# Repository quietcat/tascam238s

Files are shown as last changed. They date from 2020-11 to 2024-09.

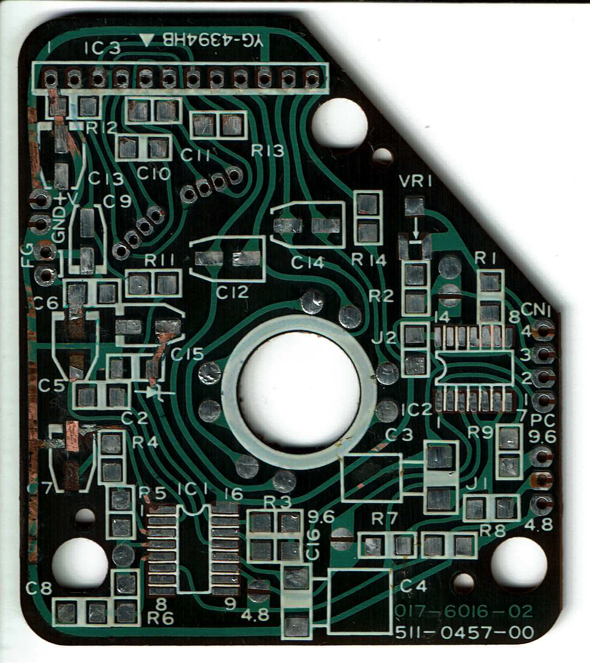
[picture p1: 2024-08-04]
capstan-pcb/238 capstan PCB 3.png

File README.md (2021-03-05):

# The Missing Tascam 238S Service Manual
Tascam 238S schematics and additional information. The Dolby S daughtercards are also used in Tascam MSR

## rp-amp-pcb

https://github.com/quietcat/tascam238s/blob/main/rp-amp-pcb.pdf

Contains Kicad schematics for the part of Tascam 238S channel PCB that is different from the dbx version

## dolby-hic

https://github.com/quietcat/tascam238s/blob/main/dolby-hic.pdf

Contains Kicad schematics for Dolby S NR HIC PCB, a Dolby encoder/decoder daughtercard for Tascam 238S

https://github.com/quietcat/tascam238s/tree/main/dolby-hic/gerbers contains Gerber files for a replacement Dolby PCB. The layout is different from the original, but functionally it is the same.

Visit https://238pro.com for more information on Tascam 238/238S repair and service

## 238S Calibration

First, calibrate the unit with Dolby S out.

Set all channels to recording mode, then press Pause and Record.

Feed -10 dBV/0 dBVU 400Hz (316 mV RMS) signal to the line inputs, and use ENC ADJ trimmer to adjust AC voltage on TP1 to be 388 mV.

Use ENC OUT trimmer to adjust AC voltage on REC LEVEL trimmer input lead (closest to the front) to be the same in both Dolby IN and OUT modes on each channel.

With Dolby S OUT, make a recording of -10 dBV/0 dBVU 400Hz test tone on all channels.

Set Dolby to IN, play back the recording and use DEC ADJ trimmer to adjust AC voltage on TP1 to be 388 mV on all channels.

Use DEC OUT trimmer to set voltage on the line out to -10 dBV (316 mV) on all channels.

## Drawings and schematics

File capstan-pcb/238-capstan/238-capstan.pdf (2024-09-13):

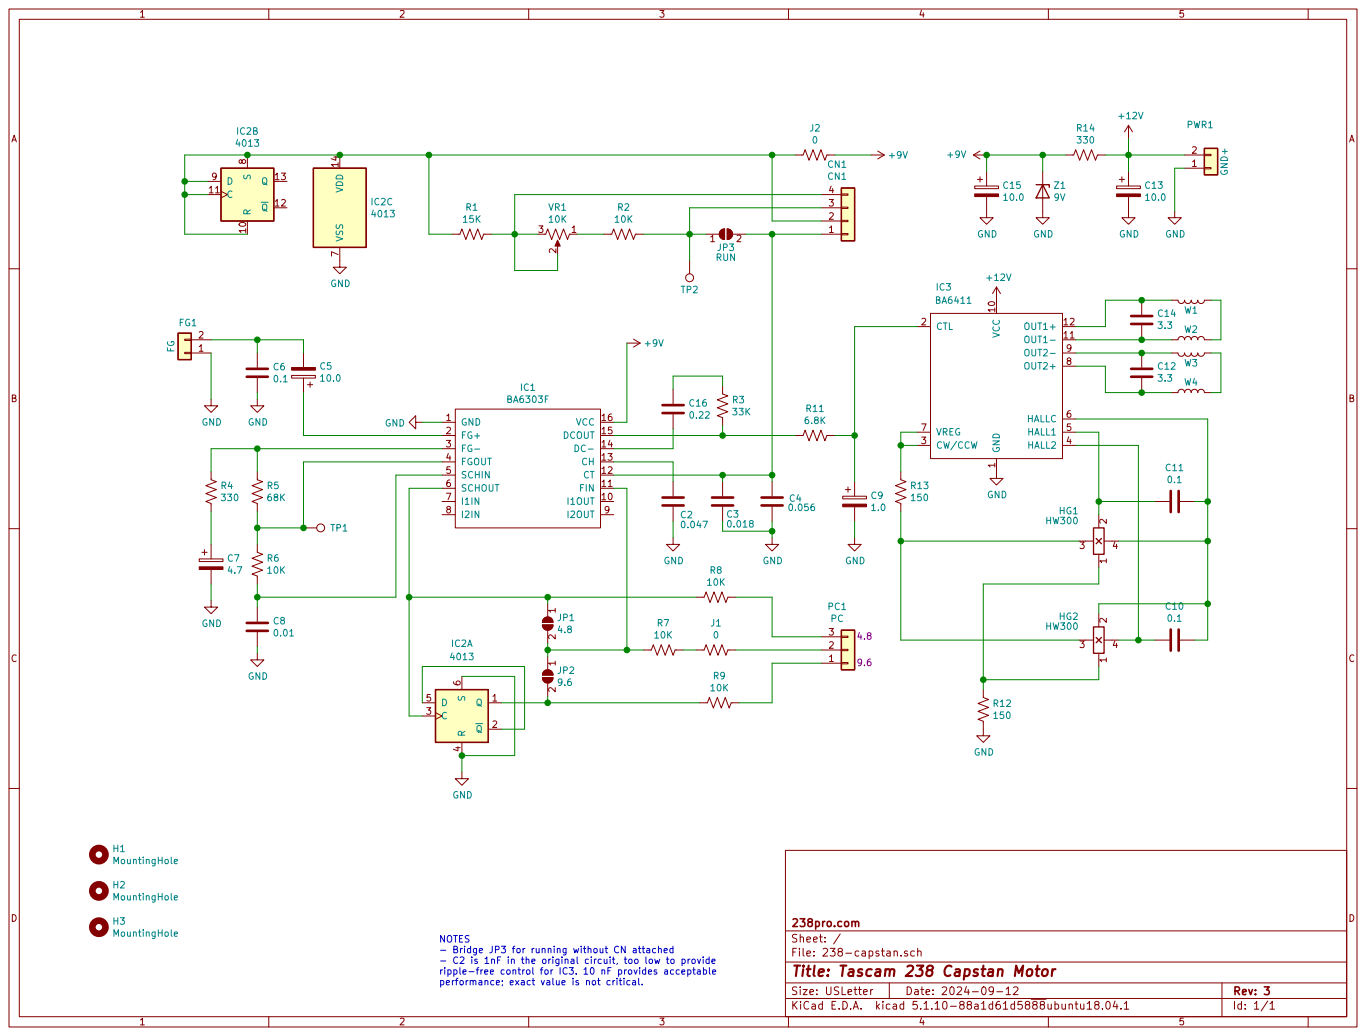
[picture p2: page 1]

1 VCC 10 OUT1- 11 OUT1+ 12 CTL 2 CW/CCW 3 HALL2 4 HALL1 5 HALLC 6 VREG 7 OUT2+ 8 OUT2- 9

File: 238-capstan.sch Sheet: / 238pro.com

NOTES
- Bridge JP3 for running without CN attached
- C2 is 1nF in the original circuit, too low to provide
ripple-free control for IC3. 10 nF provides acceptable
performance; exact value is not critical.

Id: 1/1 Title: Tascam 238 Capstan Motor

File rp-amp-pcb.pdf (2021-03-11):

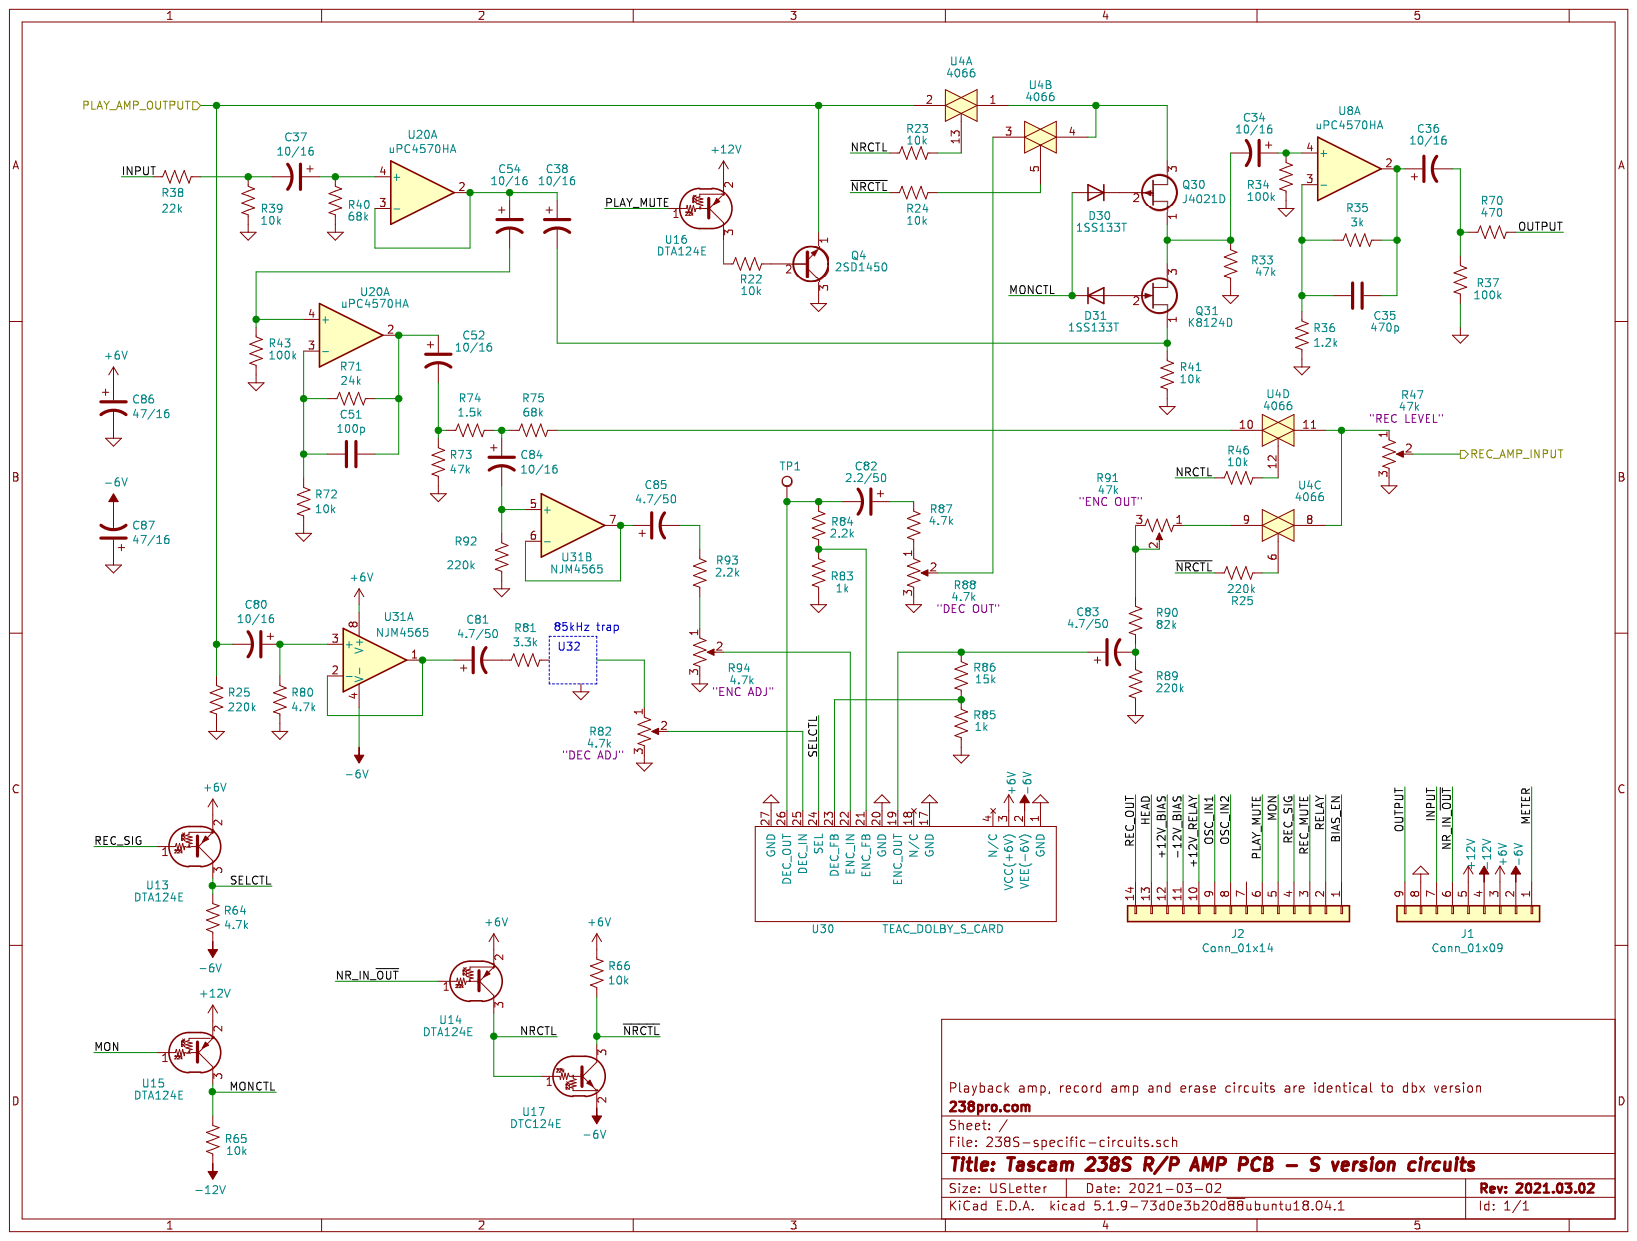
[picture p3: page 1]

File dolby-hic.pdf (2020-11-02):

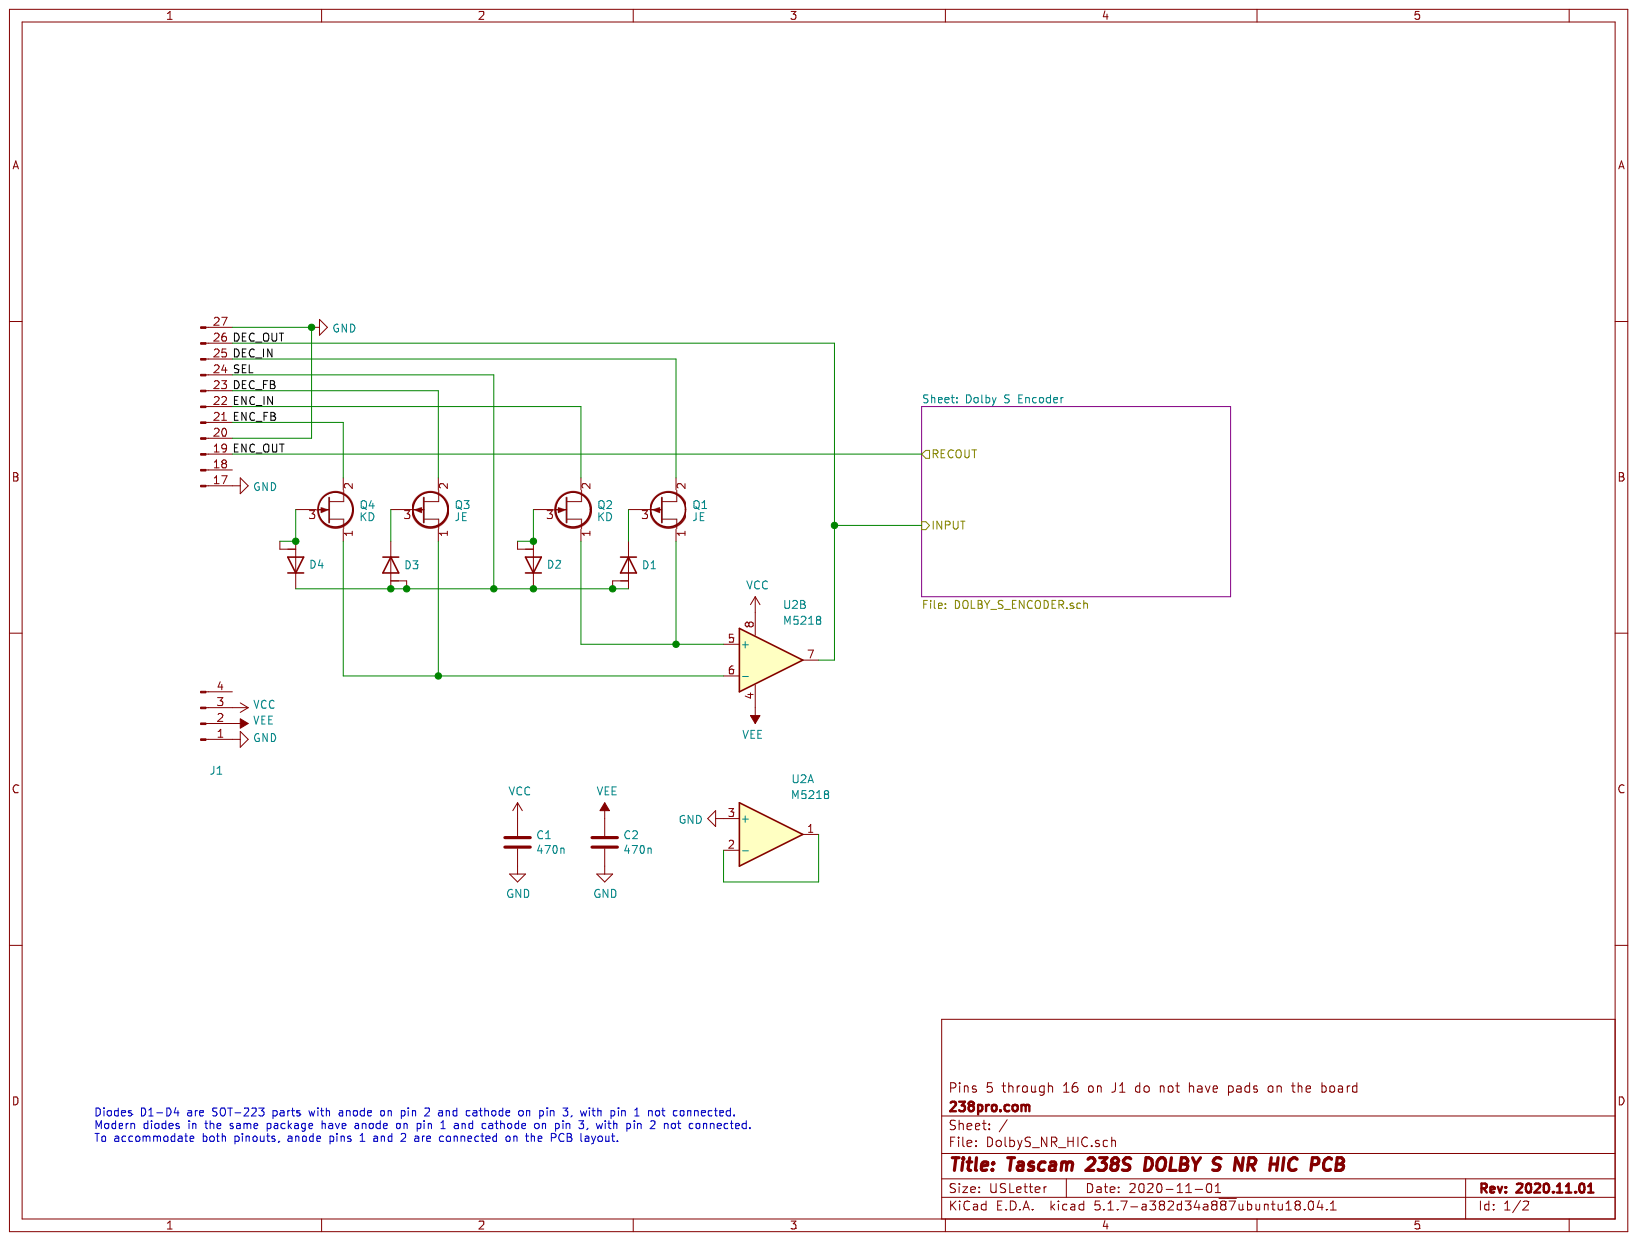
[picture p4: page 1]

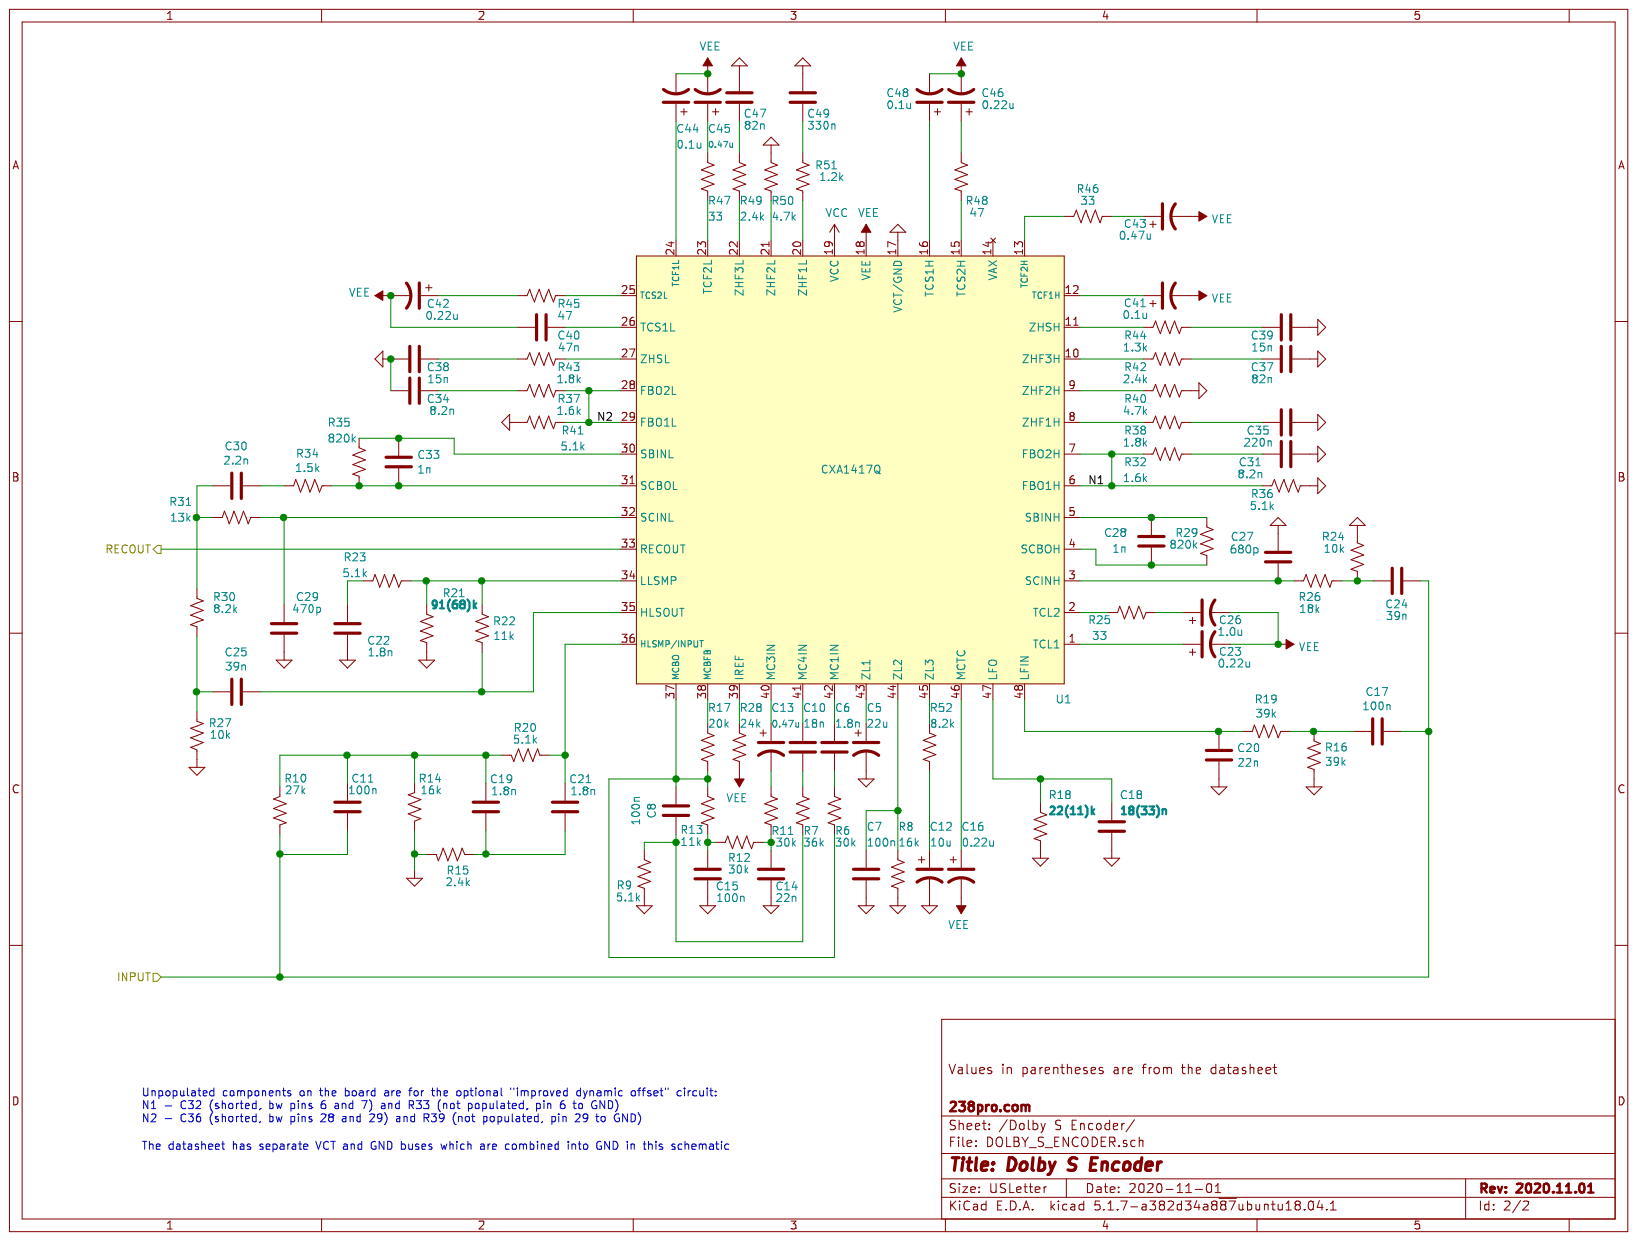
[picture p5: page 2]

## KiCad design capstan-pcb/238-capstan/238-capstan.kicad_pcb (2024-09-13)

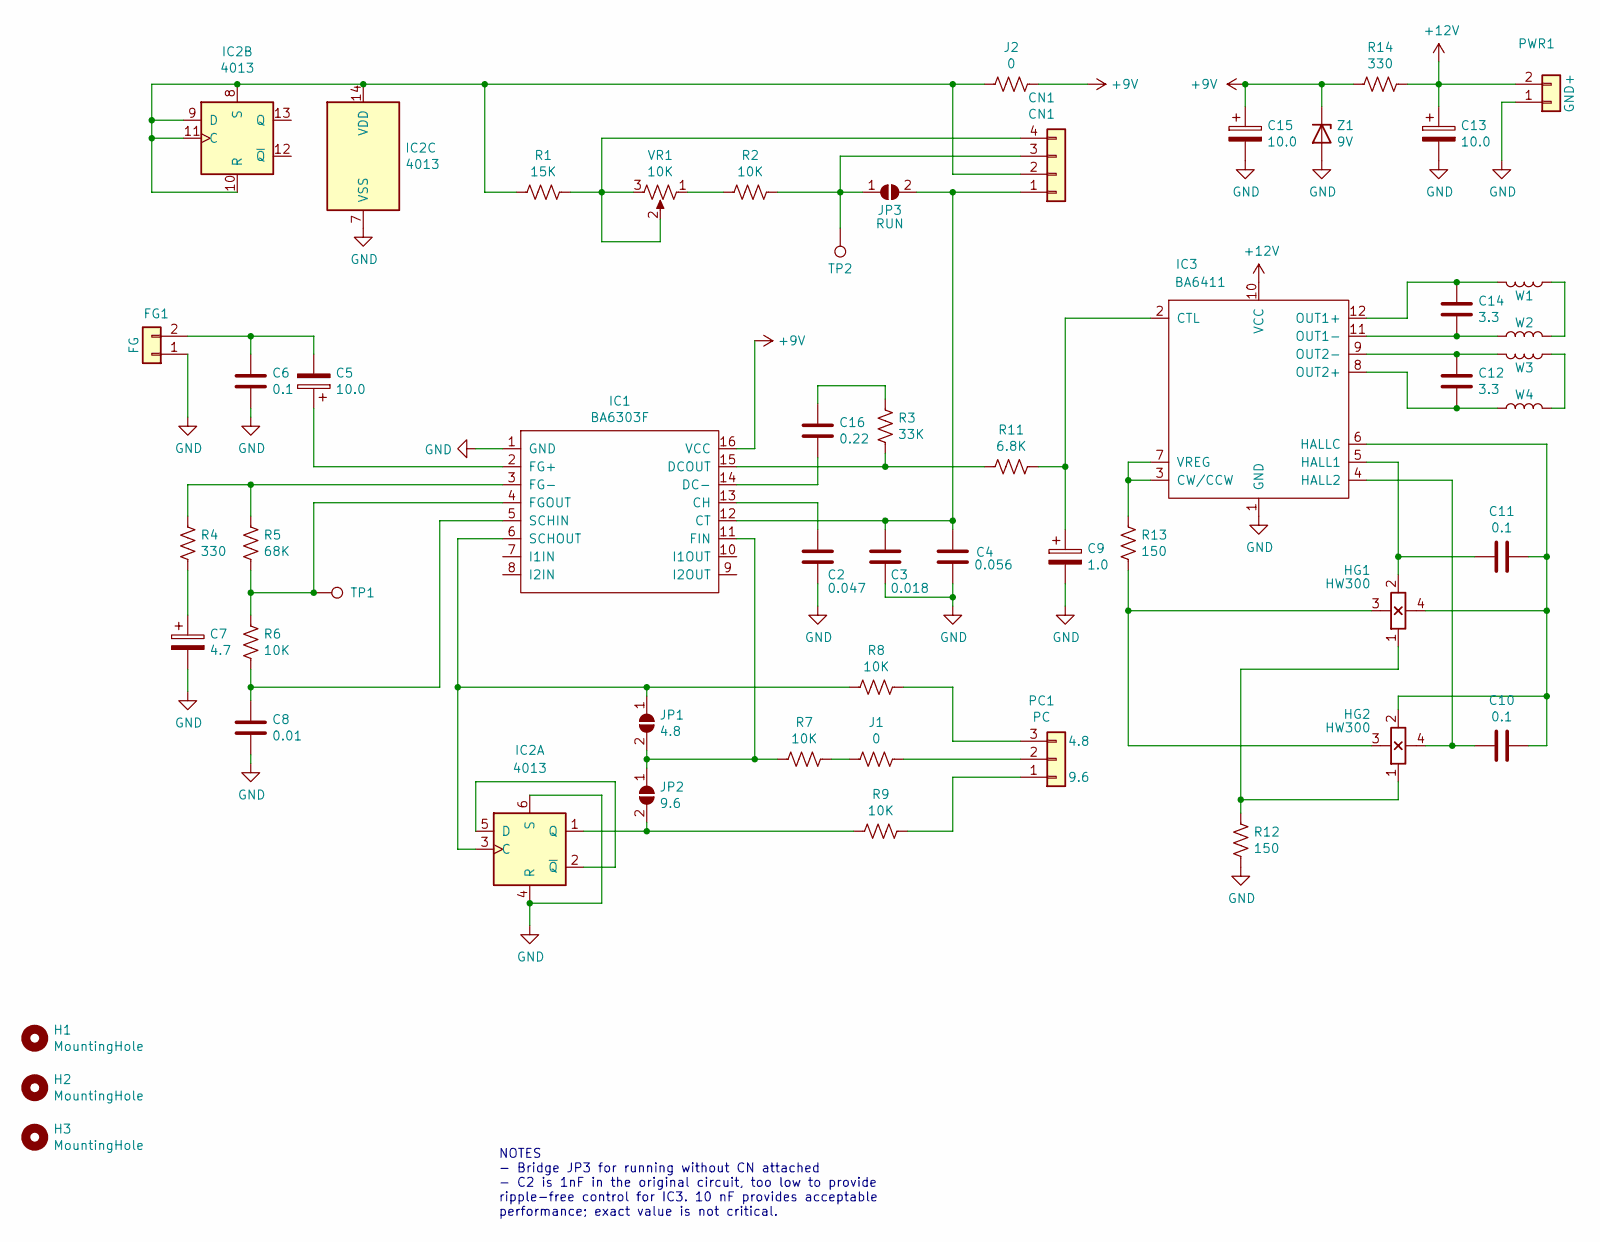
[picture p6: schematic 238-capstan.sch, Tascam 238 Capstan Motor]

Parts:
C2: 0.047; C_1206_3216Metric_Pad1.33x1.80mm_HandSolder
C3: 0.018; 238_C3
C4: 0.056; 238_C4
C5, C13, C15: 10.0; CP_Elec_4x5.3
C6, C10, C11: 0.1; C_1206_3216Metric_Pad1.33x1.80mm_HandSolder
C7: 4.7; CP_Elec_4x5.3
C8: 0.01; C_1206_3216Metric_Pad1.33x1.80mm_HandSolder
C9: 1.0; CP_Elec_4x5.3
C12, C14: 3.3; CP_Elec_4x5.3
C16: 0.22; C_1206_3216Metric_Pad1.33x1.80mm_HandSolder
CN1: CN1; 238_4_wire_conn
FG1: FG; 238_2_wire_conn
H1, H2, H3: MountingHole; MountingHole_2.1mm
HG1, HG2: HW300
IC1: BA6303F; SOIC-16_4.55x10.3mm_P1.27mm
IC2: 4013; SO-14_5.3x10.2mm_P1.27mm
IC3: BA6411
J1, J2: 0; R_1206_3216Metric_Pad1.30x1.75mm_HandSolder
JP1: 4.8; SolderJumper-2_P1.3mm_Open_RoundedPad1.0x1.5mm
JP2: 9.6; SolderJumper-2_P1.3mm_Open_RoundedPad1.0x1.5mm
JP3: RUN; SolderJumper-2_P1.3mm_Open_RoundedPad1.0x1.5mm
PC1: PC; 238_3_wire_conn
PWR1: GND+; 238_2_wire_conn
R1: 15K; R_1206_3216Metric_Pad1.30x1.75mm_HandSolder
R2, R6, R7, R8, R9: 10K; R_1206_3216Metric_Pad1.30x1.75mm_HandSolder
R3: 33K; R_1206_3216Metric_Pad1.30x1.75mm_HandSolder
R4, R14: 330; R_1206_3216Metric_Pad1.30x1.75mm_HandSolder
R5: 68K; R_1206_3216Metric_Pad1.30x1.75mm_HandSolder
R11: 6.8K; R_1206_3216Metric_Pad1.30x1.75mm_HandSolder
R12, R13: 150; R_1206_3216Metric_Pad1.30x1.75mm_HandSolder
TP1: TP1; TestPoint_Pad_D1.5mm
TP2: TP2; TestPoint_Pad_D2.5mm
VR1: 10K; Potentiometer_Bourns_TC33X_Vertical
W1, W2, W3, W4: W; 238_winding
Z1: 9V; D_MiniMELF

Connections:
+9V: C15.1, IC1.16 (VCC), J2.1, R14.2, Z1.1 (K)
+12V: C13.1, IC3.10 (VCC), PWR1.2, R14.1
GND: C2.2, C3.1, C4.2, C6.2, C7.2, C8.2, C9.2, C13.2, C15.2, FG1.1, IC1.1 (GND), IC2.4 (R), IC2.6 (S), IC2.7 (VSS), IC3.1 (GND), PWR1.1, R12.2, Z1.2 (A)
unnamed: C2.1, IC1.13 (CH)
unnamed: C3.2, C4.1, CN1.1, IC1.12 (CT), JP3.2 (B)
unnamed: C5.1, IC1.2 (FG+)
unnamed: C5.2, C6.1, FG1.2
unnamed: C7.1, R4.2
unnamed: C8.1, IC1.5 (SCHIN), R6.2
unnamed: C9.1, IC3.2 (CTL), R11.1
unnamed: C10.1, HG2.4 (UH2), IC3.4 (HALL2)
unnamed: C10.2, C11.2, HG1.4 (UH2), HG2.2 (U2), IC3.6 (HALLC)
unnamed: C11.1, HG1.2 (U2), IC3.5 (HALL1)
unnamed: C12.1, IC3.8 (OUT2+), W4.1
unnamed: C12.2, IC3.9 (OUT2-), W3.2
unnamed: C14.1, IC3.11 (OUT1-), W2.1
unnamed: C14.2, IC3.12 (OUT1+), W1.2
unnamed: C16.1, R3.1
unnamed: C16.2, IC1.14 (DC-)
unnamed: CN1.2, IC2.8 (S), IC2.9 (D), IC2.10 (R), IC2.11 (C), IC2.14 (VDD), J2.2, R1.2
unnamed: CN1.3, JP3.1 (A), R2.1, TP2.1
unnamed: CN1.4, R1.1, VR1.2, VR1.3
unnamed: HG1.1 (U1), HG2.1 (U1), R12.1
unnamed: HG1.3 (UH1), HG2.3 (UH1), R13.2
unnamed: IC1.3 (FG-), R4.1, R5.1
unnamed: IC1.4 (FGOUT), R5.2, R6.1, TP1.1
unnamed: IC1.6 (SCHOUT), IC2.3 (C), JP1.1 (A), R8.2
unnamed: IC1.11 (FIN), JP1.2 (B), JP2.1 (A), R7.2
unnamed: IC1.15 (DCOUT), R3.2, R11.2
unnamed: IC2.1 (Q), JP2.2 (B), R9.2
unnamed: IC2.2 (~Q), IC2.5 (D)
unnamed: IC3.3 (CW/CCW), IC3.7 (VREG), R13.1
unnamed: J1.1, PC1.2
unnamed: J1.2, R7.1
unnamed: PC1.1, R9.1
unnamed: PC1.3, R8.1
unnamed: R2.2, VR1.1
unnamed: W1.1, W2.2
unnamed: W3.1, W4.2

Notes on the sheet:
NOTES - Bridge JP3 for running without CN attached - C2 is 1nF in the original circuit, too low to provide ripple-free control for IC3. 10 nF provides acceptable performance; exact value is not critical.

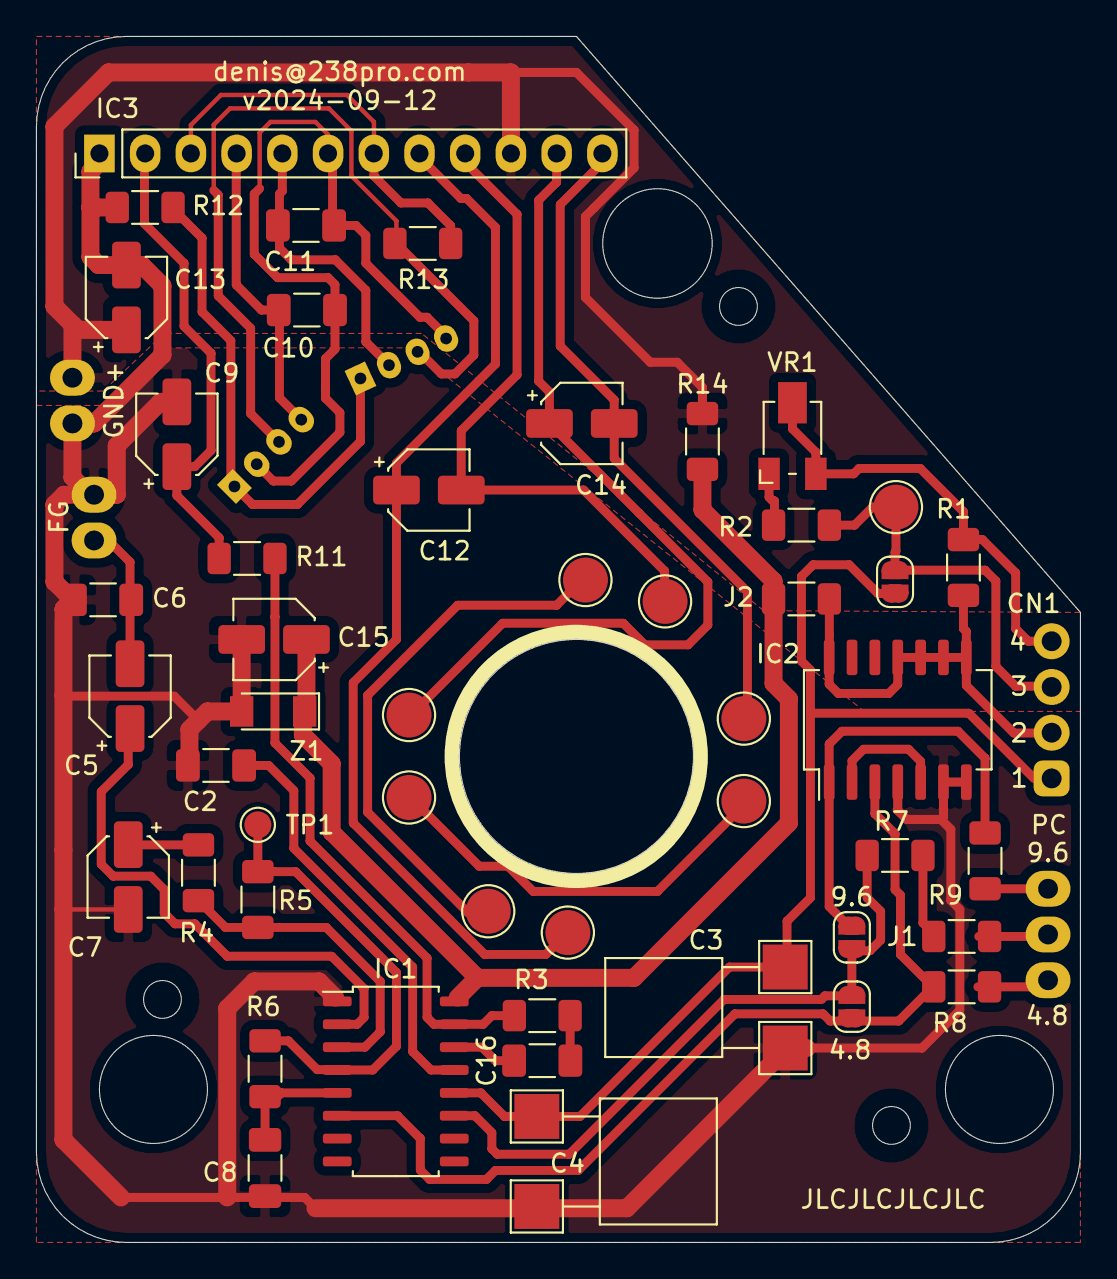
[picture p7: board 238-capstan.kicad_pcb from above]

Board: 2 copper layers, 58.0 x 67.0 mm, 53 parts (0 on the bottom side), 39 nets.

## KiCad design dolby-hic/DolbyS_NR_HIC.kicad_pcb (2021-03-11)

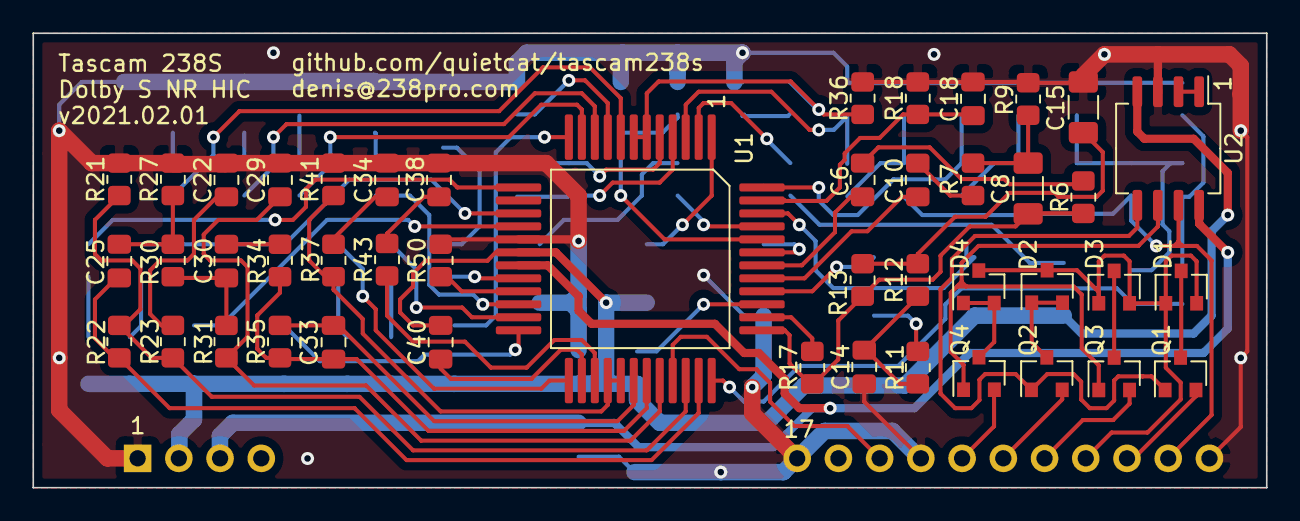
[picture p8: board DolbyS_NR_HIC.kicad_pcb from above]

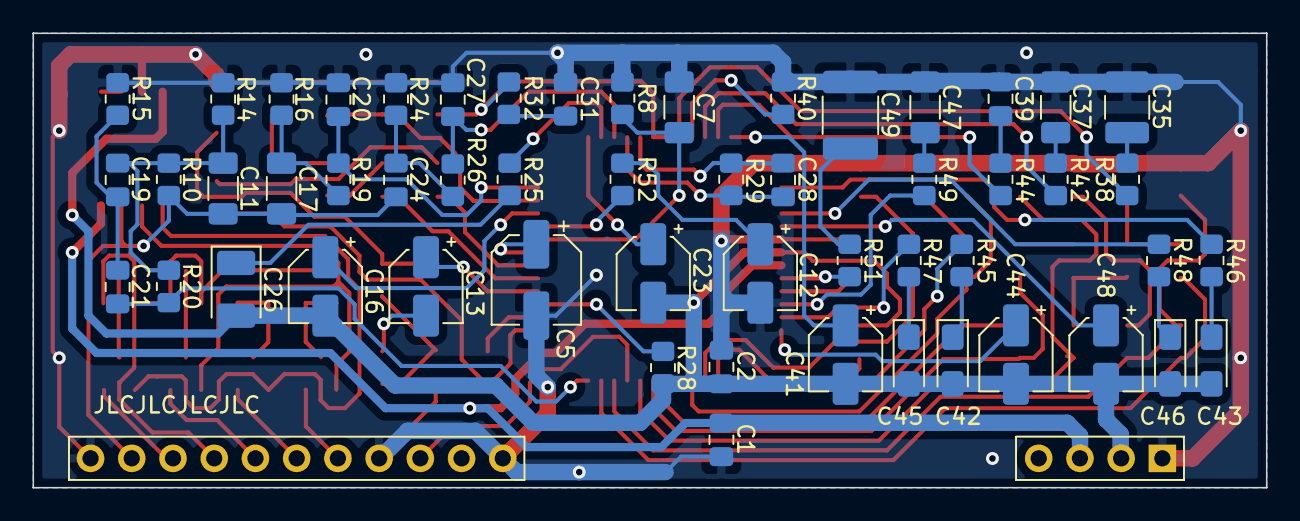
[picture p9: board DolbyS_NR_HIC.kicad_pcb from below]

Board: 2 copper layers, 76.0 x 28.0 mm, 100 parts (55 on the bottom side), 86 nets.

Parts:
C1, C2: 470n; C_0805_2012Metric_Pad1.18x1.45mm_HandSolder
C5: 22u; CP_Elec_5x5.8
C6, C19, C21, C22: 1.8n; C_0805_2012Metric_Pad1.18x1.45mm_HandSolder
C7, C8, C11, C15, C17: 100n; C_1206_3216Metric_Pad1.33x1.80mm_HandSolder
C10: 18n; C_0805_2012Metric_Pad1.18x1.45mm_HandSolder
C12: 10u; CP_Elec_4x5.8
C13: 0.47u; CP_Elec_4x5.8
C14, C20: 22n; C_0805_2012Metric_Pad1.18x1.45mm_HandSolder
C16, C23: 0.22u; CP_Elec_4x5.8
C18: 18(33)n; C_0805_2012Metric_Pad1.18x1.45mm_HandSolder
C24, C25: 39n; C_0805_2012Metric_Pad1.18x1.45mm_HandSolder
C26: 1.0u; CP_EIA-3528-21_Kemet-B_Pad1.50x2.35mm_HandSolder
C27: 680p; C_0805_2012Metric_Pad1.18x1.45mm_HandSolder
C28, C33: 1n; C_0805_2012Metric_Pad1.18x1.45mm_HandSolder
C29: 470p; C_0805_2012Metric_Pad1.18x1.45mm_HandSolder
C30: 2.2n; C_0805_2012Metric_Pad1.18x1.45mm_HandSolder
C31, C34: 8.2n; C_0805_2012Metric_Pad1.18x1.45mm_HandSolder
C35: 220n; C_1210_3225Metric_Pad1.33x2.70mm_HandSolder
C37, C47: 82n; C_1206_3216Metric_Pad1.33x1.80mm_HandSolder
C38, C39: 15n; C_0805_2012Metric_Pad1.18x1.45mm_HandSolder
C40: 47n; C_0805_2012Metric_Pad1.18x1.45mm_HandSolder
C41, C44, C48: 0.1u; CP_Elec_4x5.8
C42, C46: 0.22u; CP_EIA-3216-18_Kemet-A_Pad1.58x1.35mm_HandSolder
C43, C45: 0.47u; CP_EIA-3216-18_Kemet-A_Pad1.58x1.35mm_HandSolder
C49: 330n; C_1812_4532Metric
D1, D2, D3, D4: MMBD914; SOT-23
J1: DOLBY_S_CONN
Q1, Q3: MMBFJ270; SOT-23
Q2, Q4: MMBFJ201; SOT-23
R6, R11, R12: 30k; R_0805_2012Metric_Pad1.20x1.40mm_HandSolder
R7: 36k; R_0805_2012Metric_Pad1.20x1.40mm_HandSolder
R8, R14: 16k; R_0805_2012Metric_Pad1.20x1.40mm_HandSolder
R9, R20, R23, R36, R41: 5.1k; R_0805_2012Metric_Pad1.20x1.40mm_HandSolder
R10: 27k; R_0805_2012Metric_Pad1.20x1.40mm_HandSolder
R13, R22: 11k; R_0805_2012Metric_Pad1.20x1.40mm_HandSolder
R15, R42, R49: 2.4k; R_0805_2012Metric_Pad1.20x1.40mm_HandSolder
R16, R19: 39k; R_0805_2012Metric_Pad1.20x1.40mm_HandSolder
R17: 20k; R_0805_2012Metric_Pad1.20x1.40mm_HandSolder
R18: 22(11)k; R_0805_2012Metric_Pad1.20x1.40mm_HandSolder
R21: 91(68)k; R_0805_2012Metric_Pad1.20x1.40mm_HandSolder
R24, R27: 10k; R_0805_2012Metric_Pad1.20x1.40mm_HandSolder
R25, R46, R47: 33; R_0805_2012Metric_Pad1.20x1.40mm_HandSolder
R26: 18k; R_0805_2012Metric_Pad1.20x1.40mm_HandSolder
R28: 24k; R_0805_2012Metric_Pad1.20x1.40mm_HandSolder
R29, R35: 820k; R_0805_2012Metric_Pad1.20x1.40mm_HandSolder
R30, R52: 8.2k; R_0805_2012Metric_Pad1.20x1.40mm_HandSolder
R31: 13k; R_0805_2012Metric_Pad1.20x1.40mm_HandSolder
R32, R37: 1.6k; R_0805_2012Metric_Pad1.20x1.40mm_HandSolder
R34: 1.5k; R_0805_2012Metric_Pad1.20x1.40mm_HandSolder
R38, R43: 1.8k; R_0805_2012Metric_Pad1.20x1.40mm_HandSolder
R40, R50: 4.7k; R_0805_2012Metric_Pad1.20x1.40mm_HandSolder
R44: 1.3k; R_0805_2012Metric_Pad1.20x1.40mm_HandSolder
R45, R48: 47; R_0805_2012Metric_Pad1.20x1.40mm_HandSolder
R51: 1.2k; R_0805_2012Metric_Pad1.20x1.40mm_HandSolder
U1: CXA1417Q; QFP-48_12x12mm_P0.8mm
U2: NE5532A; SO-8_5.3x6.2mm_P1.27mm

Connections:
/DEC_FB: J1.23, Q3.2
/DEC_IN: J1.25, Q1.2
/DEC_OUT: C11.1, C17.1, C24.2, J1.26, R10.1, U2.7
/Dolby S Encoder/N1: R32.2, R36.2, U1.6, U1.7
/Dolby S Encoder/N2: R37.1, R41.1, U1.28, U1.29
/ENC_FB: J1.21, Q4.2
/ENC_IN: J1.22, Q2.2
/ENC_OUT: J1.19, U1.33
/SEL: D1.1, D1.2, D2.3, D3.1, D3.2, D4.3, J1.24
GND: C1.2, C2.2, C5.2, C7.2, C12.2, C14.2, C15.2, C18.2, C20.2, C22.2, C27.2, C29.2, C31.1, C34.2, C35.1, C37.1, C38.2, C39.1, C47.1, C49.1, J1.1, J1.17, J1.20, J1.27, R8.2, R9.1, R14.1, R15.1, R16.1, R18.2, R21.2, R24.2, R27.1, R36.1, R40.1, R41.2, R50.1, U1.17, U2.3
unnamed: C5.1, U1.43
unnamed: C6.1, U1.42
unnamed: C6.2, R6.1
unnamed: C7.1, R8.1, U1.44
unnamed: C8.1, R7.2, R9.2
unnamed: C8.2, R6.2, R13.2, R17.2, U1.37
unnamed: C10.1, U1.41
unnamed: C10.2, R7.1
unnamed: C11.2, C19.1, R10.2, R14.2, R20.1
unnamed: C12.1, R52.2
unnamed: C13.1, U1.40
unnamed: C13.2, R11.1
unnamed: C14.1, R11.2, R12.2
unnamed: C15.1, R12.1, R13.1
unnamed: C16.1, U1.46
unnamed: C17.2, R16.2, R19.1
unnamed: C18.1, R18.1, U1.47
unnamed: C19.2, C21.2, R15.2
unnamed: C20.1, R19.2, U1.48
unnamed: C21.1, R20.2, U1.36
unnamed: C22.1, R23.2
unnamed: C23.1, U1.1
unnamed: C24.1, R24.1, R26.1
unnamed: C25.1, R22.2, U1.35
unnamed: C25.2, R27.2, R30.2
unnamed: C26.1, R25.2
unnamed: C27.1, R26.2, U1.3
unnamed: C28.1, R29.1, U1.4
unnamed: C28.2, R29.2, U1.5
unnamed: C29.1, R31.1, U1.32
unnamed: C30.1, R34.2
unnamed: C30.2, R30.1, R31.2
unnamed: C31.2, R32.1
unnamed: C33.1, R35.1, U1.30
unnamed: C33.2, R34.1, R35.2, U1.31
unnamed: C34.1, R37.2
unnamed: C35.2, R38.1
unnamed: C37.2, R42.1
unnamed: C38.1, R43.2
unnamed: C39.2, R44.1
unnamed: C40.1, U1.26
unnamed: C41.1, U1.12
unnamed: C42.1, R45.2
unnamed: C43.1, R46.1
unnamed: C44.1, U1.24
unnamed: C45.1, R47.1
unnamed: C46.1, R48.1
unnamed: C47.2, R49.1
unnamed: C48.1, U1.16
unnamed: C49.2, R51.1
unnamed: D1.3, Q1.3
unnamed: D2.1, D2.2, Q2.3
unnamed: D3.3, Q3.3
unnamed: D4.1, D4.2, Q4.3
unnamed: Q1.1, Q2.1, U2.5
unnamed: Q3.1, Q4.1, U2.6
unnamed: R17.1, U1.38
unnamed: R21.1, R22.1, R23.1, U1.34
unnamed: R25.1, U1.2
unnamed: R28.1, U1.39
unnamed: R38.2, U1.8
unnamed: R40.2, U1.9
unnamed: R42.2, U1.10
unnamed: R43.1, U1.27
unnamed: R44.2, U1.11
unnamed: R45.1, U1.25
unnamed: R46.2, U1.13
unnamed: R47.2, U1.23
unnamed: R48.2, U1.15
unnamed: R49.2, U1.22
unnamed: R50.2, U1.21
unnamed: R51.2, U1.20
unnamed: R52.1, U1.45
unnamed: U2.1, U2.2
VCC: C1.1, J1.3, U1.19, U2.8
VEE: C2.1, C16.2, C23.2, C26.2, C40.2, C41.2, C42.2, C43.2, C44.2, C45.2, C46.2, C48.2, J1.2, R28.2, U1.18, U2.4

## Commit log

2020-10-24 Add values
    [238S.sch]
2020-10-25 Latest schematics
    [238S.sch]
2020-10-25 Updated version on Dolby hic
    [DOLBY_S_ENCODER.sch]
2020-10-26 Fixed version on hic main page
    [DolbyS_NR_HIC.sch]
2020-10-28 Fix swapped pins on transistors on hic; add clarification about GND and VCT buses on hic
    [DOLBY_S_ENCODER.sch, DolbyS_NR_HIC.sch]
2020-10-28 Add pdf versions of the schematics; remove blank page layout description file
2020-11-01 Version 2020.10.30 of schematic - fixed error in input circuit on HIC; HIC pcb version 2020.10.31 with gerbers sent to fab
    [DOLBY_S_ENCODER.sch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]
2020-11-02 Minor clarification updates to the hic
    [DOLBY_S_ENCODER.sch, DolbyS_NR_HIC.sch]
2020-11-04 Minor PCB rouing change, eliminated two vias
    [DolbyS_NR_HIC.kicad_pcb]
2020-11-14 Update README.md
    Added calibration procedure from the website
2021-01-12 dolby-hic PCB version 2021.01.10 - moved all electrolytical caps to the back of the board; both chips and input switching transistors on the front
    [DOLBY_S_ENCODER.sch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]
2021-03-05 Update README to reflect new knowledge on calibration process
2021-03-11 Updated HIC layout; RP amp clarification
    [238S-specific-circuits.sch, DolbyS_NR_HIC.kicad_pcb, DolbyS_NR_HIC.sch]
2024-08-04 Added capstan PCB design v2024-08-03
    [238-capstan-B_Cu.gbl, 238-capstan-B_Mask.gbs, 238-capstan-B_Paste.gbp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]
2024-08-06 Capstan pcb v2024-08-04
    [238-capstan.kicad_pcb, 238-capstan.sch]
2024-08-06 Capstan PCB v2024-08-06
    [238-capstan.kicad_pcb]
2024-08-06 Capstan PCB v2024-08-06 pour +12V
    [238-capstan.kicad_pcb]
2024-08-07 Capstan PCB - fix copper pour DRC errors, fix ground routing and keepout areas around FG input
    [238-capstan.kicad_pcb]
2024-08-14 Capstan PCB fix mouting hole position; larger pads for VR1; routing adjustments
    [238-capstan.kicad_pcb]
2024-08-16 Capstan PCB gerbers v2024-08-15, minor tweaks, sent to fab
    [238-capstan-B_Cu.gbl, 238-capstan-B_Mask.gbs, 238-capstan-B_Paste.gbp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]
2024-08-28 Add capstan pcb PDF
    [238-capstan.sch]
2024-09-13 Capstan PCB v2024-09-11, clarified schematic
    [238-capstan.kicad_pcb, 238-capstan.sch]
2024-09-13 Capstan PCB gerbers v2024-09-12
    [238-capstan-B_Cu.gbl, 238-capstan-B_Mask.gbs, 238-capstan-B_Paste.gbp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]
